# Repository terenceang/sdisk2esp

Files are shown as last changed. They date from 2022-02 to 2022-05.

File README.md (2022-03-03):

# SDISK2 ESP

## An Apple 2 floppy Emulator using ESP32.

This an update the original SDISK2 project by Koichi Nishida (2013).  
It uses it to read the Disk controller signals and return the track data from the disk image.  
A basic UI will be used to select and load an image.

### Todo

1. UI
2. Decode Disk images
3. Disk II emulation.

### Parts

1. ESP32 dev kit 1
2. SSD1306 i2c OLED module.
3. SDcard Module
4. TP223 x 3
5. SN74CB3T3245

Original SDISK II project.
https://tulip-house.ddo.jp/digital/SDISK2/english.html

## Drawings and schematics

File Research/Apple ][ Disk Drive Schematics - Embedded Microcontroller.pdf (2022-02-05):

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

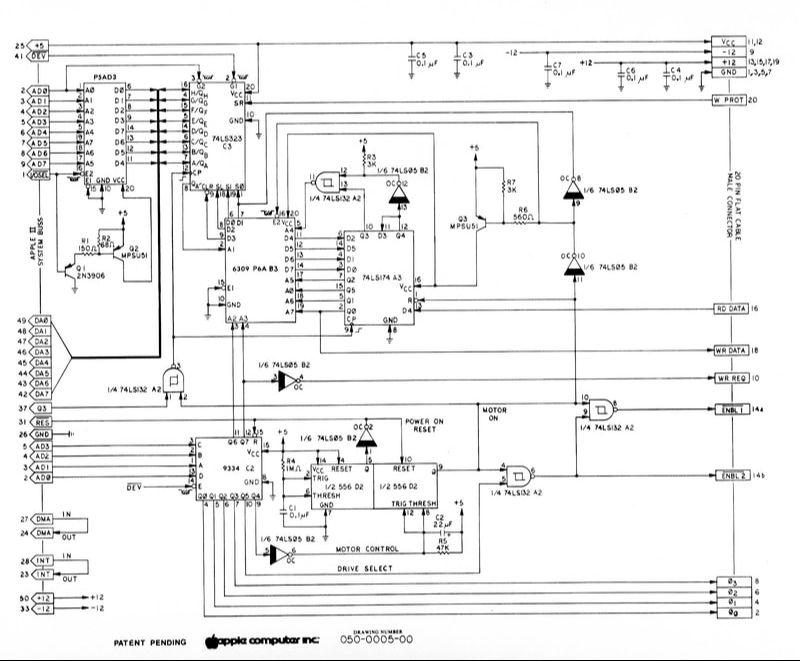
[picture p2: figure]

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

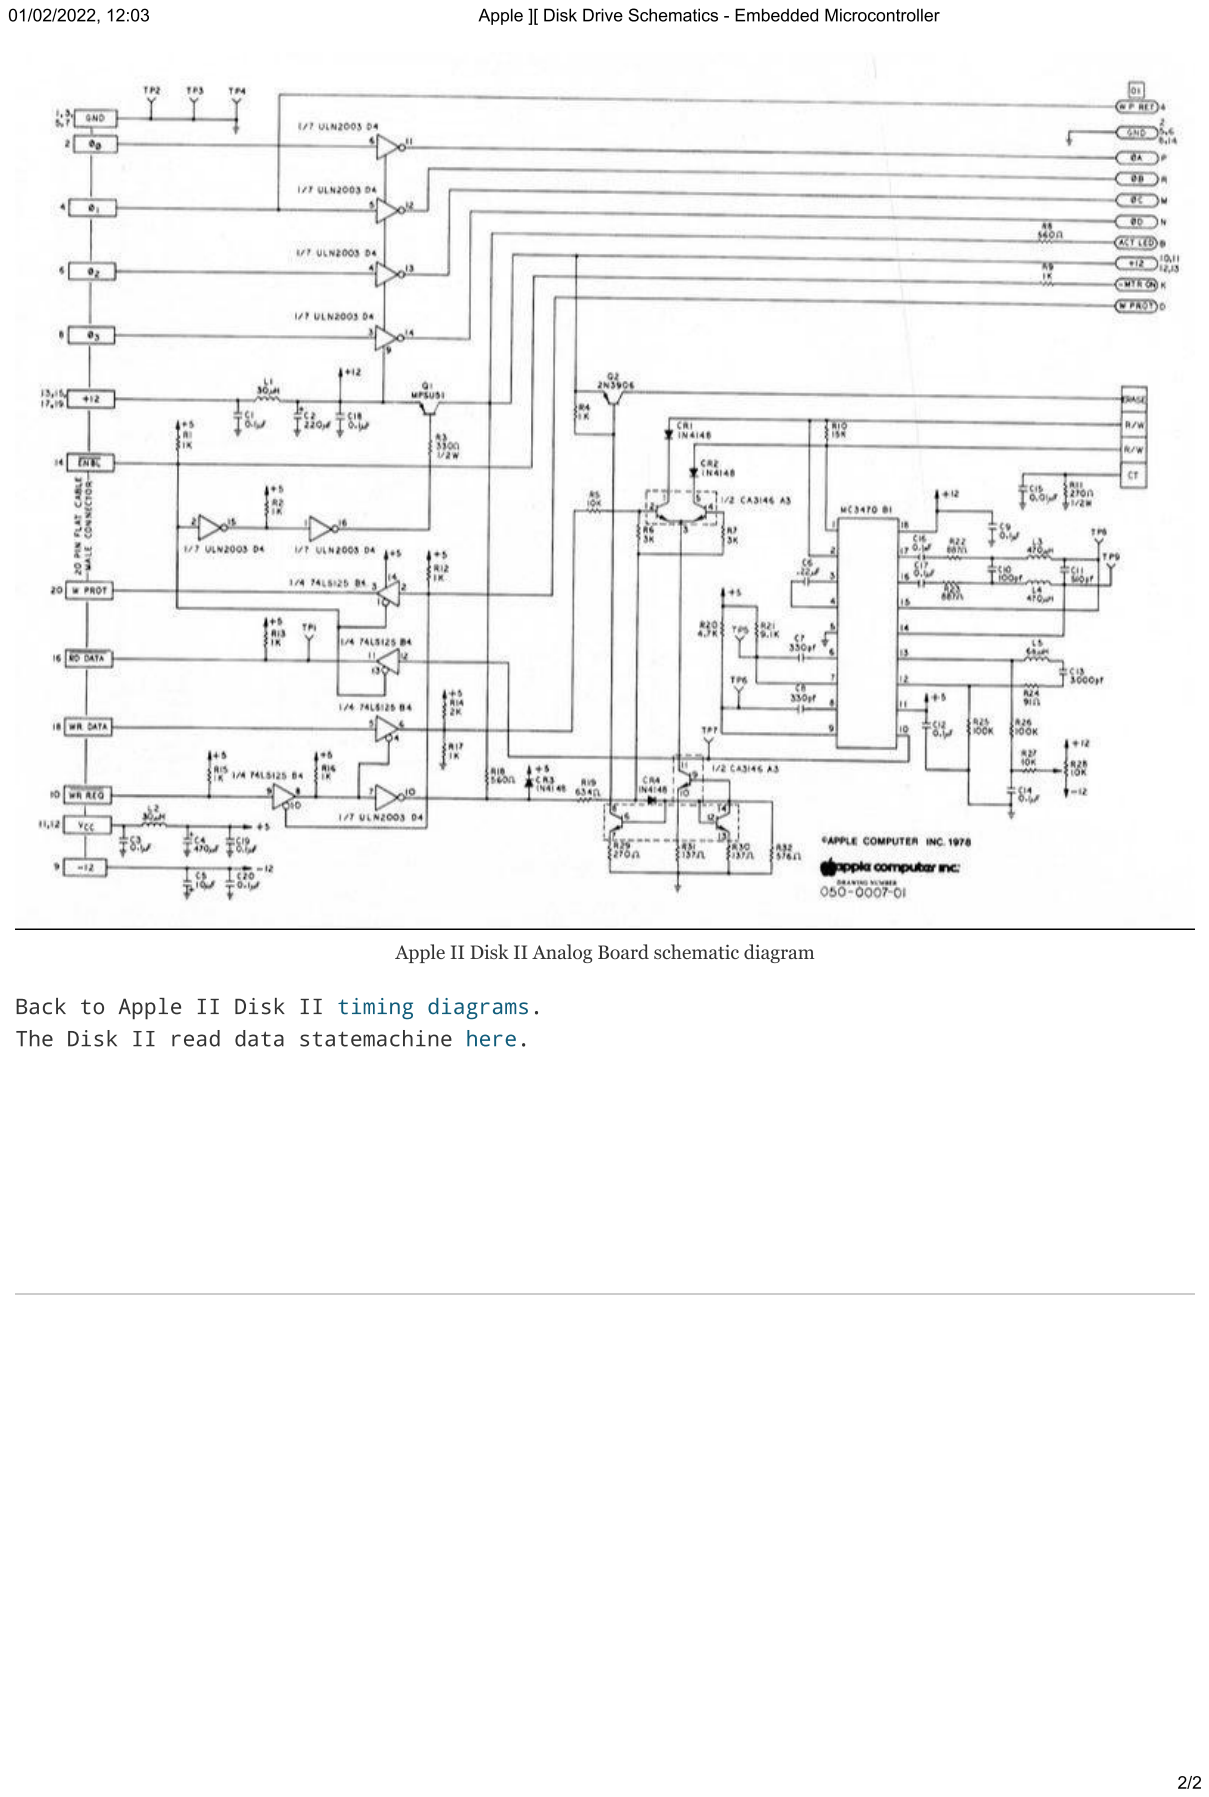
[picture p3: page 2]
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

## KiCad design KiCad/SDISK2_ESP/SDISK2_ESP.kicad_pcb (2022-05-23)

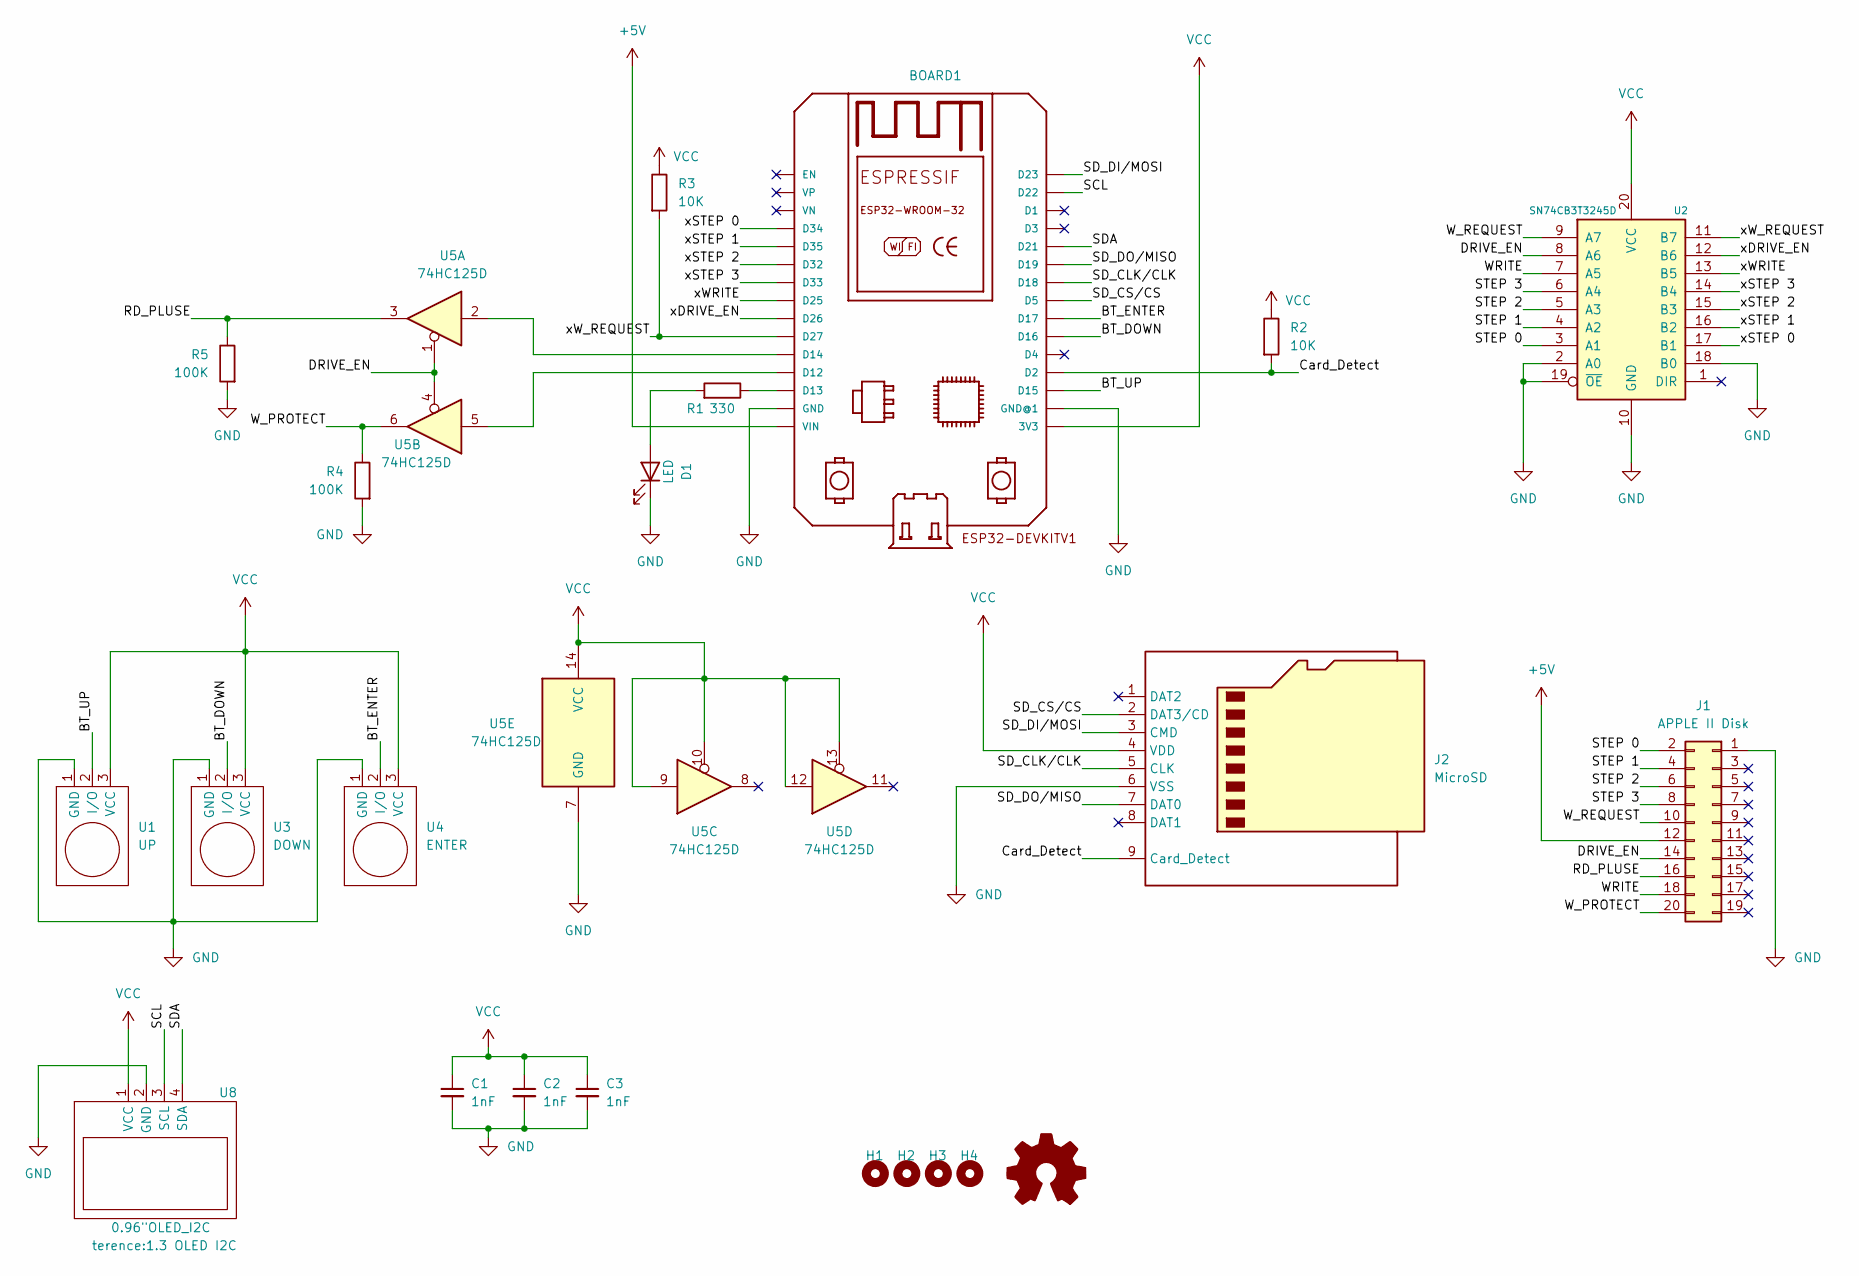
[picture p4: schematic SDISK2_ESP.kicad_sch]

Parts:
BOARD1: ESP32DEVKITV1; ESP32-DEVKITV1
C1, C2, C3: 1nF; C_0805_2012Metric
D1: LED; LED_0805_2012Metric
H1, H2, H3, H4: MountingHole; MountingHole_3mm
J1: APPLE II Disk; IDC-Header_2x10_P2.54mm_Horizontal
J2: MicroSD
LOGO1: Logo_Open_Hardware_Small; OSHW-Symbol_6.7x6mm_SilkScreen
R1: 330; R_0805_2012Metric
R2, R3: 10K; R_0805_2012Metric
R4, R5: 100K; R_0805_2012Metric
U1: UP; TP223
U2: SN74CB3T3245D; SOIC-20W_7.5x12.8mm_P1.27mm
U3: DOWN; TP223
U4: ENTER; TP223
U5: 74HC125D; SOIC-14_3.9x8.7mm_P1.27mm
U8: 0.96"OLED_I2C; 1.3 OLED I2C

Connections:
+5V: BOARD1.VIN, J1.12
/BT_DOWN: BOARD1.D16, U3.2 (I/O)
/BT_ENTER: BOARD1.D17, U4.2 (I/O)
/BT_UP: BOARD1.D15, U1.2 (I/O)
/Card_Detect: BOARD1.D2, J2.9 (Card_Detect), R2.2
/DRIVE_EN: J1.14, U2.8 (A6), U5.1, U5.4
/RD_PLUSE: J1.16, R5.1, U5.3
/SCL: BOARD1.D22, U8.3 (SCL); also elsewhere on the board
/SDA: BOARD1.D21, U8.4 (SDA); also elsewhere on the board
/SD_CLK/CLK: BOARD1.D18, J2.5 (CLK)
/SD_CS/CS: BOARD1.D5, J2.2 (DAT3/CD)
/SD_DI/MOSI: BOARD1.D23, J2.3 (CMD)
/SD_DO/MISO: BOARD1.D19, J2.7 (DAT0)
/STEP 0: J1.2, U2.3 (A1)
/STEP 1: J1.4, U2.4 (A2)
/STEP 2: J1.6, U2.5 (A3)
/STEP 3: J1.8, U2.6 (A4)
/WRITE: J1.18, U2.7 (A5)
/W_PROTECT: J1.20, R4.1, U5.6
/W_REQUEST: J1.10, U2.9 (A7)
/xDRIVE_EN: BOARD1.D26, U2.12 (B6)
/xSTEP 0: BOARD1.D34, U2.17 (B1)
/xSTEP 1: BOARD1.D35, U2.16 (B2)
/xSTEP 2: BOARD1.D32, U2.15 (B3)
/xSTEP 3: BOARD1.D33, U2.14 (B4)
/xWRITE: BOARD1.D25, U2.13 (B5)
/xW_REQUEST: BOARD1.D27, R3.2, U2.11 (B7)
GND: BOARD1.GND, BOARD1.GND@1, C1.2, C2.2, C3.2, D1.1 (K), J1.1, J2.6 (VSS), R4.2, R5.2, U1.1 (GND), U2.2 (A0), U2.10 (GND), U2.18 (B0), U2.19 (~OE), U3.1 (GND), U4.1 (GND), U5.7 (GND), U8.2 (GND); also elsewhere on the board
unnamed: BOARD1.D12, U5.5
unnamed: BOARD1.D13, R1.1
unnamed: BOARD1.D14, U5.2
unnamed: D1.2 (A), R1.2
VCC: BOARD1.3V3, C1.1, C2.1, C3.1, J2.4 (VDD), R2.1, R3.1, U1.3 (VCC), U2.20 (VCC), U3.3 (VCC), U4.3 (VCC), U5.9, U5.10, U5.12, U5.13, U5.14 (VCC), U8.1 (VCC); also elsewhere on the board

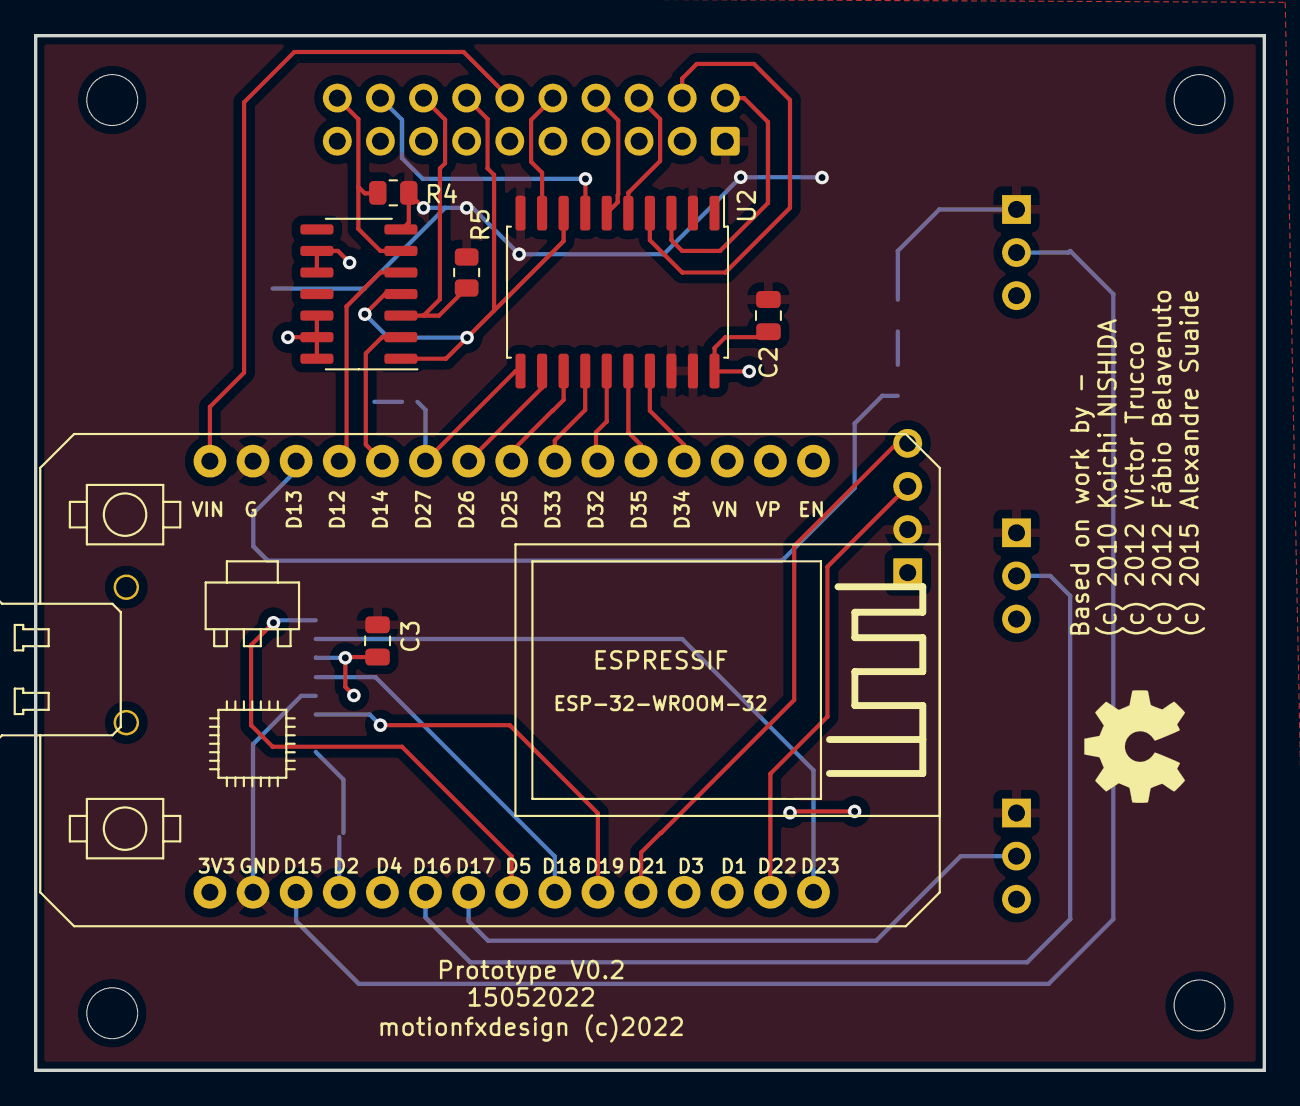
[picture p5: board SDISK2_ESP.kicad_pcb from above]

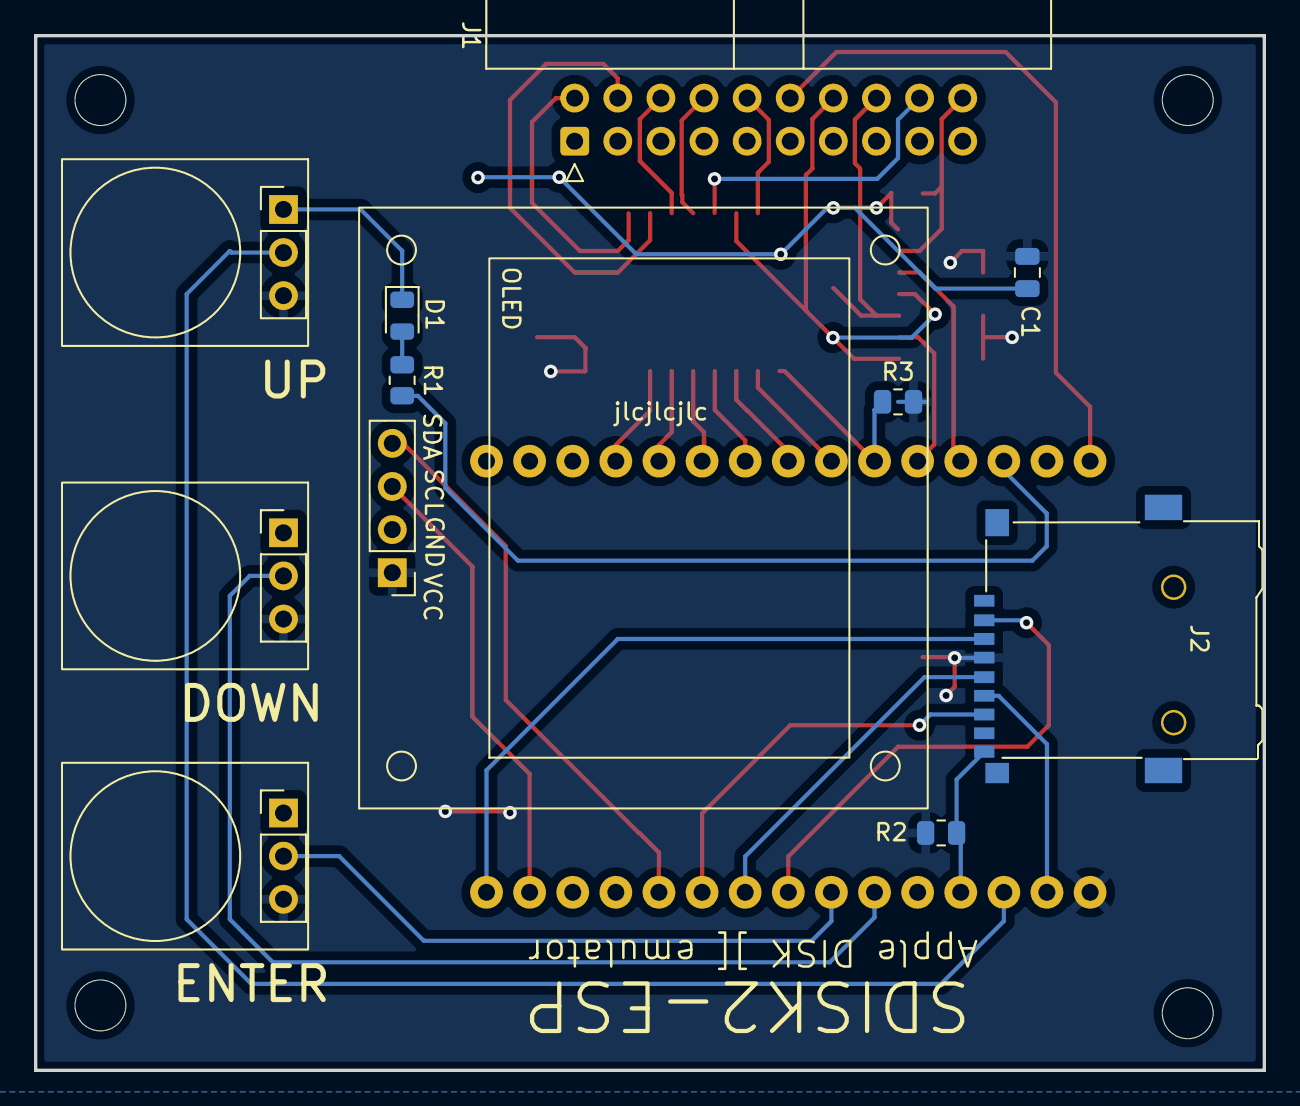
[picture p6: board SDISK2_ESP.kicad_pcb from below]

Board: 2 copper layers, 72.4 x 61.0 mm, 23 parts (11 on the bottom side), 33 nets.

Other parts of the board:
OLED: 0.96"OLED_I2C; 1.3 OLED I2C

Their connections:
/SCL: OLED.3 (SCL); also elsewhere on the board
/SDA: OLED.4 (SDA); also elsewhere on the board
GND: OLED.2 (GND); also elsewhere on the board
VCC: OLED.1 (VCC); also elsewhere on the board

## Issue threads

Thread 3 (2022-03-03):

Compiler warnings -  [-Wincompatible-pointer-types]

terenceang, 2022-03-03:
warning attempt to assign an unsigned char pointer to int pointer.
```
main.c: In function ‘select_nic’:
main.c:1009:11: warning: assignment from incompatible pointer type [-Wincompatible-pointer-types]
  files_id = &writeData[2][0];
           ^
```

you can leave it or change file_id to unsigned char*

Closed 2022-03-03.

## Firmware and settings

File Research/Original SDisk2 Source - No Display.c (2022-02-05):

/*------------------------------------------------------------

	DISK II Emulator Farmware (1 of 2) for ATMEGA328P

	version 2.3	2013.10.30 by Koichi Nishida
	require version 2.0 hardware

	Copyright 2013 Koichi NISHIDA
	email to Koichi NISHIDA: tulip-house@msf.biglobe.ne.jp
	
------------------------------------------------------------*/

/*
hardware information:

use ATMEGA328P AVR.
connect 27MHz (overclock...) crystal to the AVR.
supply 3.3V power.

fuse setting : LOW 11011110

connection:
	<connection to SD card using spi>
	B2: CS (SS)
	B3: DI (MOSI)
	B4: DO (MISO)
	B5: SCLK (SCK)
	D6: LOCK
	
	<connections to APPLE II disk IF>
	B1: WRITE
	C0: PHASE-0
	C1: PHASE-1
	C2: PHASE-2
	C3: PHASE-3
	C4: READ PULSE (through 74HC125 3state)
	D2(INT0): WRITE REQUEST (10K ohm pull up for open collector)
	D3: EJECT
	D4: WRITE PROTECT (through 74HC125 3state)
	D7: DRIVE ENABLE
	
	<others>
	D5: LED
	C5: connect to C6 (RESET) for software reset
	
	Note that the enable input of the 3state buffer 74HC125,
	should be connected with DRIVE ENABLE.
*/

#include <avr/io.h>
#include <avr/interrupt.h>
#include <avr/pgmspace.h>
#include <avr/eeprom.h>

#define nop() __asm__ __volatile__ ("nop")
#define WAIT 1

// write buffer number
#define BUF_NUM 5

// fat buffer size
#define FAT_DSK_SIZE 18
#define FAT_NIC_SIZE 35

// for selecting SD card
#define SD_CS	2	// PB2 SS	CS

// C prototypes

// ===== low level SD card functions =====

// cancel read
void cancelRead(void);
// write a byte data to the SD card
void writeByte(unsigned char c);
// read data from the SD card
unsigned char readByte(void);
// wait until finish a command
void waitFinish(void);
// issue SD card command without getting response
void cmd_(unsigned char cmd, unsigned long adr);
// issue SD card command  and wait normal response
void cmd(unsigned char cmd, unsigned long adr);
// get command response from the SD card
unsigned char getResp(void);
// issue command 17 and get ready for reading
void cmd17(unsigned long adr);
// find a file extension

// ===== file manipulate functions =====

int findExt(char *str, unsigned char *protect, unsigned char *name);
// prepare the FAT table on memory
void prepareFat(int i, unsigned short *fat, unsigned short len,
	unsigned char fatNum, unsigned char fatElemNum);
// memory copy	
void memcp(unsigned char *dst, unsigned char *src, const unsigned short len);
// duplicate FAT for FAT16
void duplicateFat(void);
// write to the SD cart one by one
void writeSD(unsigned long adr, unsigned char *data, unsigned short len);
// create a NIC image file
int createNic(unsigned char *name);
// translate a NIC image into a DSK image
void nic2Dsk(void);
// translate a DSK image into a NIC image
void dsk2Nic(void);

// ===== SDISK II main functions =====

// initialization SD
int SDinit(void);
// write data back to a NIC image
// set write pointer and write back if need
void buffering(void);
void writeBack(void);
void writeBackSub(unsigned char bn, unsigned char sc, unsigned char track);
// buffer clear
void buffClear(void);

// assembler functions
void wait5(unsigned short time);

// ===== data area =====

// SD card information
unsigned long bpbAddr, rootAddr;
unsigned long fatAddr;									// the beginning of FAT
unsigned char sectorsPerCluster, sectorsPerCluster2;	// sectors per cluster
unsigned short sectorsPerFat;	
unsigned long userAddr;									// the beginning of user data
// unsigned short fatDsk[FAT_DSK_SIZE];					// use writeData instead
unsigned short fatNic[FAT_NIC_SIZE];
unsigned char prevFatNumDsk, prevFatNumNic;
unsigned short nicDir, dskDir;

// DISK II status
volatile unsigned char ph_track;		// 0 - 139
unsigned char sector;					// 0 - 15
unsigned short bitbyte;					// 0 - (8*512-1)
unsigned char prepare;
unsigned char readPulse;
unsigned char magState;
unsigned char protect;
unsigned char formatting;
const unsigned char volume = 0xfe;

// track number is stored on eeprom.
#define EEP_PH_TRACK (uint8_t *)0x0001

// write data buffer
unsigned char writeData[BUF_NUM][350];
unsigned char sectors[BUF_NUM], tracks[BUF_NUM];
unsigned char buffNum;
unsigned char *writePtr;
unsigned char doBuffering;

// a table for head stepper moter movement 
PROGMEM prog_uchar stepper_table[4] = {0x0f,0xed,0x03,0x21};

// encode / decode table for a nib image
PROGMEM prog_uchar encTable[] = {
	0x96,0x97,0x9A,0x9B,0x9D,0x9E,0x9F,0xA6,
	0xA7,0xAB,0xAC,0xAD,0xAE,0xAF,0xB2,0xB3,
	0xB4,0xB5,0xB6,0xB7,0xB9,0xBA,0xBB,0xBC,
	0xBD,0xBE,0xBF,0xCB,0xCD,0xCE,0xCF,0xD3,
	0xD6,0xD7,0xD9,0xDA,0xDB,0xDC,0xDD,0xDE,
	0xDF,0xE5,0xE6,0xE7,0xE9,0xEA,0xEB,0xEC,
	0xED,0xEE,0xEF,0xF2,0xF3,0xF4,0xF5,0xF6,
	0xF7,0xF9,0xFA,0xFB,0xFC,0xFD,0xFE,0xFF
};
PROGMEM prog_uchar decTable[] = {
	0x00,0x00,0x00,0x00,0x00,0x00,0x00,0x00,0x00,0x00,0x00,0x00,0x00,0x00,0x00,0x00,
	0x00,0x00,0x00,0x00,0x00,0x00,0x00,0x00,0x00,0x00,0x00,0x00,0x00,0x00,0x00,0x00,
	0x00,0x00,0x00,0x00,0x00,0x00,0x00,0x00,0x00,0x00,0x00,0x00,0x00,0x00,0x00,0x00,
	0x00,0x00,0x00,0x00,0x00,0x00,0x00,0x00,0x00,0x00,0x00,0x00,0x00,0x00,0x00,0x00,
	0x00,0x00,0x00,0x00,0x00,0x00,0x00,0x00,0x00,0x00,0x00,0x00,0x00,0x00,0x00,0x00,
	0x00,0x00,0x00,0x00,0x00,0x00,0x00,0x00,0x00,0x00,0x00,0x00,0x00,0x00,0x00,0x00,
	0x00,0x00,0x00,0x00,0x00,0x00,0x00,0x00,0x00,0x00,0x00,0x00,0x00,0x00,0x00,0x00,
	0x00,0x00,0x00,0x00,0x00,0x00,0x00,0x00,0x00,0x00,0x00,0x00,0x00,0x00,0x00,0x00,
	0x00,0x00,0x00,0x00,0x00,0x00,0x00,0x00,0x00,0x00,0x00,0x00,0x00,0x00,0x00,0x00,
	0x00,0x00,0x00,0x00,0x00,0x00,0x00,0x01,0x00,0x00,0x02,0x03,0x00,0x04,0x05,0x06,
	0x00,0x00,0x00,0x00,0x00,0x00,0x07,0x08,0x00,0x00,0x00,0x09,0x0a,0x0b,0x0c,0x0d,
	0x00,0x00,0x0e,0x0f,0x10,0x11,0x12,0x13,0x00,0x14,0x15,0x16,0x17,0x18,0x19,0x1a,
	0x00,0x00,0x00,0x00,0x00,0x00,0x00,0x00,0x00,0x00,0x00,0x1b,0x00,0x1c,0x1d,0x1e,
	0x00,0x00,0x00,0x1f,0x00,0x00,0x20,0x21,0x00,0x22,0x23,0x24,0x25,0x26,0x27,0x28,
	0x00,0x00,0x00,0x00,0x00,0x29,0x2a,0x2b,0x00,0x2c,0x2d,0x2e,0x2f,0x30,0x31,0x32,
	0x00,0x00,0x33,0x34,0x35,0x36,0x37,0x38,0x00,0x39,0x3a,0x3b,0x3c,0x3d,0x3e,0x3f
};

// a table for translating logical sectors into physical sectors
PROGMEM prog_uchar physicalSector[] = {
		0,13,11,9,7,5,3,1,14,12,10,8,6,4,2,15};

// for bit flip
PROGMEM prog_uchar FlipBit[] = { 0,  2,  1,  3  };
PROGMEM prog_uchar FlipBit1[] = { 0, 2,  1,  3  };
PROGMEM prog_uchar FlipBit2[] = { 0, 8,  4,  12 };
PROGMEM prog_uchar FlipBit3[] = { 0, 32, 16, 48 };

// buffer clear
void buffClear(void)
{
	unsigned char i;
	unsigned short j;
	
	for (i=0; i<BUF_NUM; i++)
		for (j=0; j<350; j++)
			writeData[i][j]=0;
	for (i=0; i<BUF_NUM; i++)
		sectors[i]=tracks[i]=0xff;
}

// cancel read from the SD card
void cancelRead(void)
{
	unsigned short i;
	if (bitbyte<(402*8)) {
		PORTB = 0b00011000;
		for (i=bitbyte; i<(514*8); i++) {
			PORTB = 0b00111000;
			PORTB = 0b00011000;
		}
		bitbyte = 402*8;
	}
}

// write a byte data to the SD card
void writeByte(unsigned char c)
{
	SPDR = c;
	// Wait for transmission complete
	while (!(SPSR & (1<<SPIF)))
		if (bit_is_set(PIND,3)) PORTC &= (~0b00100000);// if eject, reset
}

// read data from the SD card
unsigned char readByte(void)
{
	SPDR = 0xFF;
	// Wait for reception complete
	while (!(SPSR & (1<<SPIF)))
		if (bit_is_set(PIND,3)) PORTC &= (~0b00100000);// if eject, reset
	// Return Data Register
	return SPDR;
}

// wait until data is written to the SD card
void waitFinish(void)
{
	unsigned char ch;
	do {
		ch = readByte();
	} while (ch != 0xff);
}

// issue a SD card command without getting response
void cmd_(unsigned char cmd, unsigned long adr)
{
	writeByte(0xff);
	writeByte(0x40+cmd);
	writeByte(adr>>24);
	writeByte((adr>>16)&0xff);
	writeByte((adr>>8)&0xff);
	writeByte(adr&0xff);
	writeByte(0x95);
	writeByte(0xff);
}

// issue a SD card command and wait normal response
void cmd(unsigned char cmd, unsigned long adr)
{
	unsigned char res;
	do {
		writeByte(0xff);
		writeByte(0x40+cmd);
		writeByte(adr>>24);
		writeByte((adr>>16)&0xff);
		writeByte((adr>>8)&0xff);
		writeByte(adr&0xff);
		writeByte(0x95);
		writeByte(0xff);
	} while (((res=getResp())!=0) && (res!=0xff));
}

// get a command response from the SD card
unsigned char getResp(void)
{
	unsigned char ch;
	do {
		ch = readByte();
	} while ((ch&0x80) != 0);
	return ch;
}

// issue command 17 and get ready for reading
void cmd17(unsigned long adr)
{
	unsigned char ch;

	cmd(17, adr);
	do {	
		ch = readByte();
	} while (ch != 0xfe);
}

// find a file extension
int findExt(char *str, unsigned char *protect, unsigned char *name)
{
	short i;
	unsigned max_file = 512;
	unsigned short max_time = 0, max_date = 0;

	// find NIC extension
	for (i=0; i!=512; i++) {
		unsigned char ext[3], d;
		unsigned char time[2], date[2];
		
		// check first char
		cmd(16, 1);
		cmd17(rootAddr+i*32);
		d = readByte();
		readByte(); readByte(); // discard CRC bytes
		if ((d==0x00)||(d==0x05)||(d==0x2e)||(d==0xe5)) continue;
		if (!(((d>='A')&&(d<='Z'))||((d>='0')&&(d<='9')))) continue;
		cmd17(rootAddr+i*32+11);
		d = readByte();
		readByte(); readByte(); // discard CRC bytes
		if (d&0x1e) continue;
		if (d==0xf) continue;
		// check extension
		cmd(16, 4);
		cmd17(rootAddr+i*32+8);
		ext[0] = readByte(); ext[1] = readByte(); ext[2] = readByte();
		if (protect) *protect = ((readByte()&1)<<4); else readByte();
		readByte(); readByte(); // discard CRC bytes
		// check time stamp
		cmd(16, 4);
		cmd17(rootAddr+i*32+22);
		time[0] = readByte(); time[1] = readByte();
		date[0] = readByte(); date[1] = readByte();
		readByte(); readByte(); // discard CRC bytes
		if ((ext[0]==str[0])&&(ext[1]==str[1])&&(ext[2]==str[2])) {
			unsigned short tm = *(unsigned short *)time;
			unsigned short dt = *(unsigned short *)date;

			if ((dt>max_date)||((dt==max_date)&&(tm>=max_time))) {
				max_time = tm;
				max_date = dt;
				max_file = i;
			}
		}
	}
	if ((max_file != 512) && (name != 0)) {
		unsigned char j;
		cmd(16, 8);
		cmd17(rootAddr+max_file*32);
		for (j=0; j<8; j++) name[j] = readByte();
		readByte(); readByte();
	}
	return max_file;
	// if 512 then not found...
}

// prepare a FAT table on memory
void prepareFat(int i, unsigned short *fat, unsigned short len,
	unsigned char fatNum, unsigned char fatElemNum)
{
	unsigned short ft;
	unsigned char fn;

	cmd(16, (unsigned long)2);
	cmd17(rootAddr+i*32+26);
	ft = readByte();
	ft += (unsigned short)readByte()*0x100;
	readByte(); readByte(); // discard CRC bytes
	if (0==fatNum) fat[0] = ft;
	for (i=0; i<len; i++) {
		fn = (i+1)/fatElemNum;
		cmd17((unsigned long)fatAddr+(unsigned long)ft*2);
		ft = readByte();
		ft += (unsigned short)readByte()*0x100;
		readByte(); readByte(); // discard CRC bytes
		if (fn==fatNum) fat[(i+1)%fatElemNum] = ft;
		if ((ft>0xfff6)||(fn>fatNum)) break;
	}
	cmd(16, (unsigned long)512);	
}

// memory copy
void memcp(unsigned char *dst, unsigned char *src, unsigned short len)
{
	unsigned short i;
	
	for (i=0; i<len; i++) dst[i]=src[i];
}

void writeSD(unsigned long adr, unsigned char *data, unsigned short len)
{
	unsigned int i;
	unsigned char *buf = &writeData[0][0];

	cmd(16, 512);
	cmd17(adr&0xfffffe00);
	for (i=0; i<512; i++) buf[i] = readByte();
	readByte(); readByte(); // discard CRC bytes
	memcp(&(buf[adr&0x1ff]), data, len);
	
	PORTB |= (1<<SD_CS);
	PORTB &= ~(1<<SD_CS);
				
	cmd(24,adr&0xfffffe00);		
	writeByte(0xff);
	writeByte(0xfe);
	for (i=0; i<512; i++) writeByte(buf[i]);
	writeByte(0xff);
	writeByte(0xff);
	readByte();
	waitFinish();
	
	PORTB |= (1<<SD_CS);
	PORTB &= ~(1<<SD_CS);	
}

void duplicateFat(void)
{
	unsigned short i, j;
	unsigned long adr = fatAddr;
	unsigned char *buf = &writeData[0][0];

	cmd(16, 512);
	for (j=0; j<sectorsPerFat; j++) {
		cmd17(adr);
		for (i=0; i<512; i++) buf[i] = readByte();
		readByte(); readByte(); // discard CRC bytes

		PORTB |= (1<<SD_CS);
		PORTB &= ~(1<<SD_CS);	
	
		cmd(24,adr+(unsigned long)sectorsPerFat*512);		
		writeByte(0xff);
		writeByte(0xfe);
		for (i=0; i<512; i++) writeByte(buf[i]);
		writeByte(0xff);
		writeByte(0xff);
		readByte();
		waitFinish();
		adr += 512;

		PORTB |= (1<<SD_CS);
		PORTB &= ~(1<<SD_CS);
	}
}

// create a NIC image file
int createNic(unsigned char *name)
{
	unsigned short re, clusterNum;
	unsigned long ft, adr;
	unsigned short d, i;
	unsigned char c, dirEntry[32], at;
	static unsigned char last[2] = {0xff, 0xff};
	
	for (i=0; i<32; i++) dirEntry[i]=0;
	memcp(dirEntry, name, 8);
	memcp(dirEntry+8, (unsigned char *)"NIC", 3);
	*(unsigned long *)(dirEntry+28) = (unsigned long)286720;
	
	// search a root directory entry
	for (re=0; re<512; re++) {
		cmd(16, 1);
		cmd17(rootAddr+re*32+0);
		c = readByte();
		readByte(); readByte(); // discard CRC bytes
		cmd17(rootAddr+re*32+11);
		at = readByte();
		readByte(); readByte(); // discard CRC bytes
		if (((c==0xe5)||(c==0x00))&&(at!=0xf)) break;  // find a RDE!
	}	
	if (re==512) return 0;
	// write a directory entry
	writeSD(rootAddr+re*32, dirEntry, 32);	
	// search the first fat entry
	adr = (rootAddr+re*32+26);
	clusterNum = 0;
	for (ft=2;
		(clusterNum<((560+sectorsPerCluster-1)>>sectorsPerCluster2)); ft++) {
		cmd(16, 2);
		cmd17(fatAddr+ft*2);
		d = readByte();
		d += (unsigned short)readByte()*0x100;
		readByte(); readByte(); // discard CRC bytes
		if (d==0) {
			clusterNum++;
			writeSD(adr, (unsigned char *)&ft, 2);
			adr = fatAddr+ft*2;
		}
	}
	writeSD(adr, last, 2);
	duplicateFat();
	return 1;
}
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
int main(void)
{
	PORTB = 0b00010000;
	PORTC = 0b00100000;
	PORTD = 0b01001000;

	DDRB = 0b00101100;	
	DDRC = 0b00110000;
	DDRD = 0b00110000;

	sei();

	eeprom_busy_wait();
	ph_track = eeprom_read_byte(EEP_PH_TRACK);
	if (ph_track > 196) ph_track = 0;	
	if (ph_track > 139) ph_track = 139;

	// pc interrupt for head move
	PCMSK1 = 0b00001111;
	PCICR = (1<<PCIE1);

	unsigned long i;

	// wait long low of eject
	for (i=0; i!=0x80000;i++) {	
		if (bit_is_set(PIND,3)) {
			i=0; continue;
		}
	}
	// now SD card has been inserted completely

	// timer0 (4u sec)
	OCR0A = 108;
	TCCR0A = (1<<WGM01);
	TCCR0B = (1<<CS00);
	
	MCUCR = 0b00000010;
	
	// int0 falling edge interrupt for write request
	// int1 rising edge interrupt for eject
	EICRA = 0b00001110;

	if (SDinit()) {
		// initialize variables
		readPulse = 0;
		magState = 0;
		prepare = 1;
		bitbyte = 0;
		sector = 0;
		buffNum = 0;
		formatting = 0;
		writePtr = &(writeData[buffNum][0]);
		buffClear();
		TIMSK0 |= (1<<OCIE0A);	// on timer
		EIMSK |= (1<<INT0);	// on int0
		EIMSK |= (1<<INT1);	// on int1
		SPCR = 0; 				// off spi
	} else while (1) ;
	
	while (1) {
		if (bit_is_set(PIND, 7)) { 				// disable drive
			PORTD &= ~(0b00100000);				// LED off
		} else { 									// enable drive                                                                                                                                                                   
			PORTD |= 0b00100000;					// LED on
			if (bit_is_set(PIND,6)||protect||(PINC&2))
				PORTD |= 0b00010000;
			else
				PORTD &= ~0b00010000;
			if (prepare) {
				TIMSK0 &= ~(1<<OCIE0A);			// disable timer0
				sector = ((sector+1)&0xf);
				unsigned char trk = (ph_track>>2);
				if (!(((sectors[0]^sector)|(tracks[0]^trk)) &
					((sectors[1]^sector)|(tracks[1]^trk)) &
					((sectors[2]^sector)|(tracks[2]^trk)) &
					((sectors[3]^sector)|(tracks[3]^trk)) &
					((sectors[4]^sector)|(tracks[4]^trk))))
					writeBack();
				SPCR = ((1<<SPE)|(1<<MSTR));		// enable spi
				unsigned short long_sector = (unsigned short)trk*16+sector;
				unsigned short long_cluster = long_sector>>sectorsPerCluster2;
				unsigned char fatNum = long_cluster/FAT_NIC_SIZE;
				unsigned short ft;
				if (fatNum != prevFatNumNic) {
					prevFatNumNic = fatNum;
					prepareFat(nicDir, fatNic, (560+sectorsPerCluster-1)>>sectorsPerCluster2, fatNum, FAT_NIC_SIZE);
				}
				ft = fatNic[long_cluster%FAT_NIC_SIZE];
				cmd17(userAddr+(((unsigned long)(ft-2)<<sectorsPerCluster2)
					+ (long_sector&(sectorsPerCluster-1)))*512);
				bitbyte = 0;
				prepare = 0;
				SPCR = 0;							// disable SPI
				TIMSK0 |= (1<<OCIE0A);				// enable timer0
			}
			if (doBuffering) {
				doBuffering = 0;
				buffering();
			}
		}
	}
}

void writeBackSub(unsigned char bn, unsigned char sc, unsigned char track)
{
	unsigned char c;
	unsigned short i;
	unsigned short long_sector = (unsigned short)track*16+sc;
	unsigned short long_cluster = long_sector>>sectorsPerCluster2;
	unsigned char fatNum = long_cluster/FAT_NIC_SIZE;
	unsigned short ft;

	TIMSK0 &= ~(1<<OCIE0A);		// disable timer0
	SPCR = ((1<<SPE)|(1<<MSTR));	// enable spi

	// BPB address
	if (fatNum != prevFatNumNic) {
		prevFatNumNic = fatNum;
		prepareFat(nicDir, fatNic,
			(560+sectorsPerCluster-1)>>sectorsPerCluster2, fatNum, FAT_NIC_SIZE);
	}
	ft = fatNic[long_cluster%FAT_NIC_SIZE];
	
	PORTB |= (1<<SD_CS);
	PORTB &= ~(1<<SD_CS);

	cmd(24, (unsigned long)userAddr+(((unsigned long)(ft-2)<<sectorsPerCluster2)
		+ (unsigned long)(long_sector&(sectorsPerCluster-1)))*512);

	writeByte(0xff);
	writeByte(0xfe);
	
	// 22 ffs
	for (i = 0; i < 22; i++) {
		writeByte(0xff);
	}

	// sync header
	writeByte(0x03);
	writeByte(0xfc);
	writeByte(0xff);
	writeByte(0x3f);
	writeByte(0xcf);
	writeByte(0xf3);
	writeByte(0xfc);
	writeByte(0xff);
	writeByte(0x3f);
	writeByte(0xcf);
	writeByte(0xf3);
	writeByte(0xfc);

	// address header
	writeByte(0xd5);
	writeByte(0xAA);
	writeByte(0x96);
	writeByte((volume>>1)|0xaa);
	writeByte(volume|0xaa);
	writeByte((track>>1)|0xaa);
	writeByte(track|0xaa);
	writeByte((sc>>1)|0xaa);
	writeByte(sc|0xaa);
	c = (volume^track^sc);
	writeByte((c>>1)|0xaa);
	writeByte(c|0xaa);
	writeByte(0xde);
	writeByte(0xAA);
	writeByte(0xeb);

	// sync header
	writeByte(0xff);	
	writeByte(0xff);
	writeByte(0xff);
	writeByte(0xff);
	writeByte(0xff);

	// data
	for (i = 0; i < 349; i++) {
		c = writeData[bn][i];
		writeByte(c);
	}
	for (i = 0; i < 14; i++) {
		writeByte(0xff);
	}
	for (i = 0; i < 96; i++) {
		writeByte(0);
	}
	writeByte(0xff);
	writeByte(0xff);
	readByte();
	waitFinish();

	PORTB |= (1<<SD_CS);
	PORTB &= ~(1<<SD_CS);	

	SPCR = 0;							// disable spi
	TIMSK0 |= (1<<OCIE0A);				// enable timer0
}

// write back into the SD card
void writeBack(void)
{
	unsigned char i, j;

	for (j=0; j<BUF_NUM; j++) {
		if (sectors[j]!=0xff) {
			for (i=0; i<BUF_NUM; i++) {
				if (sectors[i] != 0xff)
					writeBackSub(i, sectors[i], tracks[i]);
				sectors[i] = 0xff;
				tracks[i] = 0xff;
				writeData[i][2]=0;
			}
			buffNum = 0;
			writePtr = &(writeData[buffNum][0]);
			break;
		}
	}
}

// set write pointer and write back if need
void buffering(void)
{
	static unsigned char sec;

	if (writeData[buffNum][2]==0xAD) {
		if (!formatting) {
			sectors[buffNum]=sector;
			tracks[buffNum]=(ph_track>>2);
			sector=((((sector==0xf)||(sector==0xd))?(sector+2):(sector+1))&0xf);
			if (buffNum == (BUF_NUM-1)) {
				// cancel reading
				cancelRead();
				writeBack();
				prepare = 1;
			} else {
				buffNum++;
				writePtr = &(writeData[buffNum][0]);
			}
		} else {
			sector = sec;
			formatting = 0;
			if (sec == 0xf) {
				// cancel reading
				cancelRead();
				prepare = 1;
			}
		}
	} if (writeData[buffNum][2]==0x96) {
		sec = (((writeData[buffNum][7]&0x55)<<1) | (writeData[buffNum][8]&0x55));
		formatting = 1;
	}
}

// reset when eject
ISR(INT1_vect)
{
	unsigned long i;

	// wait long high of eject
	for (i=0; i!=0x80000;i++)
		if (bit_is_clear(PIND,3)) return;
	// now SD card has been removed completely

	// record track number on eeprom
	eeprom_busy_wait();
	eeprom_write_byte (EEP_PH_TRACK, ph_track); 

	// and reset!
	PORTC &= (~0b00100000);
}
	
	

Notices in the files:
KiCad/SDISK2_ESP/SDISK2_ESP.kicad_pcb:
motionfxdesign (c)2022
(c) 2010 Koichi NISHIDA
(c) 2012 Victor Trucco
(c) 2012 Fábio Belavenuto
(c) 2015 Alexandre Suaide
